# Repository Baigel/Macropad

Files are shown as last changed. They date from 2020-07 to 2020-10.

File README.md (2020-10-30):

This project is modified from Mattia Dal Ben's YamPad with a few changes that suit my specific needs (credit: https://github.com/mattdibi/yampad)

The Yampad project is an open-source, [QMK (Quantum Mechanical Keyboard Firmware)](https://github.com/qmk/qmk_firmware) powered, hot-swappable, RGB-backlighted, OLED featured, mechanical numpad.

## Primary Modifications from Original YamPad
 - Added 2 more switches for an array of 4x5 buttons (no more 2u keys)
 - Added spot for an IR sensor
 - Made the unused pins more accessible (added them as expansion pins on the side; with room for a decoupling capacitor)
 - Redid the PCB design (basically designed the PCB from scratch, used Mattia Dal Ben's design as a guide)
 - Different mounting holes (in hindsight, the Pro Micro may cover the holes in the top right - Oops!)

## YamPad Features:
- Cheap to build: the PCB can be manufactured for less than 1$ per piece.
- Easy to source components.
- Easy to build.
- Hot swappable keys using *Kailh PCB sockets*.
- Arduino Pro Micro powered.
- QMK compatible.
- RGB backlighting support (optional).
- OLED 0.91" screen (optional).
- Completely open-source.

## Bill of materials

| Qty | Item | Notes |
|-----|---|---|
| 1 | Arduino Pro Micro (ATmega32u4) | a.k.a. SparkFun Pro Micro |
| 20  | Cherry MX compatible switches | |
| 20  | SOD-123 1N4148/1N4148W diodes | |
| 20  | Kailh PCB sockets CPG151101S11 | |
| 10  | WS2812B RGB LEDs | |
| 10  | SMD 0805 100nF capacitors | |
| 1 | I2C 0.91" 128*32 OLED Display Module | The ones using SSD1306 driver IC over I2C |
| 1 | 6mm*6mm button switch | |
| 1 | YamPAD/Macropad PCB | |
| 5 | M3 screws | |

Note that I have included my personal shopping list (with links) in /Macropad/Bill_of_Materials.txt for reference

## Assembly guide

Not necessary to assemble in this order. More details can be found on the official YamPad repository (https://github.com/mattdibi/yampad).

1. Start with soldering the **WS2812 LEDs**. Start by applying solder to a pad, then heat it up while adding the component, finally solder the remaining pads.
2. Now add the **0805 100nF caps**. Use the same technique as before.
3. Add the **1N4148 diodes**.
4. Add the **CPG151101S11 Kailh PCB sockets**.
5. Add the **reset 6mm button switch**.
6. Add some electrical tape just to be sure.
7. Add the **Arduino Pro Micro** bottom side up.
8. Add the **OLED screen**
9. Move to the firmware section and you should be set!

## Firmware

For now the firmware is available through mattdibi's [QMK firmware repository fork](https://github.com/mattdibi/qmk_firmware/tree/yampad).

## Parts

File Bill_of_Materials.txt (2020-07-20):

JLCPCB
 - Custom PCBs from jlcpcb; the zip file that must be uploaded can be found at [https://github.com/Baigel/Macropad/blob/master/pcb/Macropad_Gerber_Files.zip]; the default settings on https://cart.jlcpcb.com/ are fine although the dimensions must be 100mm by 100mm

 SparkFun
 - Pro Micro (microcontroller) (a.k.a. SparkFun Pro Micro)
https://www.sparkfun.com/products/15795

 - 10x WS2812B RGB LEDs (I have included multiple sources below, digikey/sparkfun is easiest, but price/availability is a little iffy)
https://www.sparkfun.com/products/13667
https://core-electronics.com.au/smd-led-rgb-ws2812b-strip-of-10.html
https://www.digikey.com.au/product-detail/en/COM-16347/1568-COM-16347CT-ND/12149781/?itemSeq=332673955

KBD Fans
 - 20x Switches (Kailh Speed Copper) (each order comes with 10, so only need to set quantity to 2)
https://kbdfans.com/products/kailh-speed-switches?variant=7133813932090

 - 20x Kailh PCB sockets CPG151101S11
https://kbdfans.com/products/mechanical-keyboard-switches-kailh-pcb-socket

BangGood
 - 1x I2C 0.91" 128*32 OLED Display Module (The ones using SSD1306 driver IC over I2C)
https://au.banggood.com/0_91-Inch-128x32-IIC-I2C-Blue-OLED-LCD-Display-DIY-Oled-Module-SSD1306-Driver-IC-DC-3_3V-5V-p-1140506.html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

Digikey
 - 1x 6mm*6mm button switch
https://www.digikey.com.au/product-detail/en/e-switch/TL3342F160QG-TR/EG2531CT-ND/379004

 - 30x SMD 0805 100nF capacitors (10 spares because these are tiny/cheap and are easily lost)
https://www.digikey.com.au/product-detail/en/kemet/C0805C104Z5VACTU/399-1177-1-ND/411452

 - 30x SOD-123 Diodes (1 per switch) (1N4148W) (10 spares because these are tiny/cheap and are easily lost)
https://www.digikey.com.au/product-detail/en/diodes-incorporated/1N4148W-13-F/1N4148W-13FDICT-ND/2242774

 - 6x Standoffs: (not sure if this is what is needed, but with a couple of m3 screws you should be able to work something out)
https://www.digikey.com.au/product-detail/en/MTS-8/RPC1574-ND/392815/?itemSeq=332685766

Price Estimate: $5 [PCB] + $8 [standoffs] + 2x$20 [Pro Micro] + 2x$3 [Switches] + 20x$0.1 [Sockets] + $4 [OLED Display] + $1 [Reset Button] + 30x$0.15 [Capacitors] + 30x$0.25 [Diodes] + $9 [RGB LEDs] + $8 [Digikey Ruler] = $92

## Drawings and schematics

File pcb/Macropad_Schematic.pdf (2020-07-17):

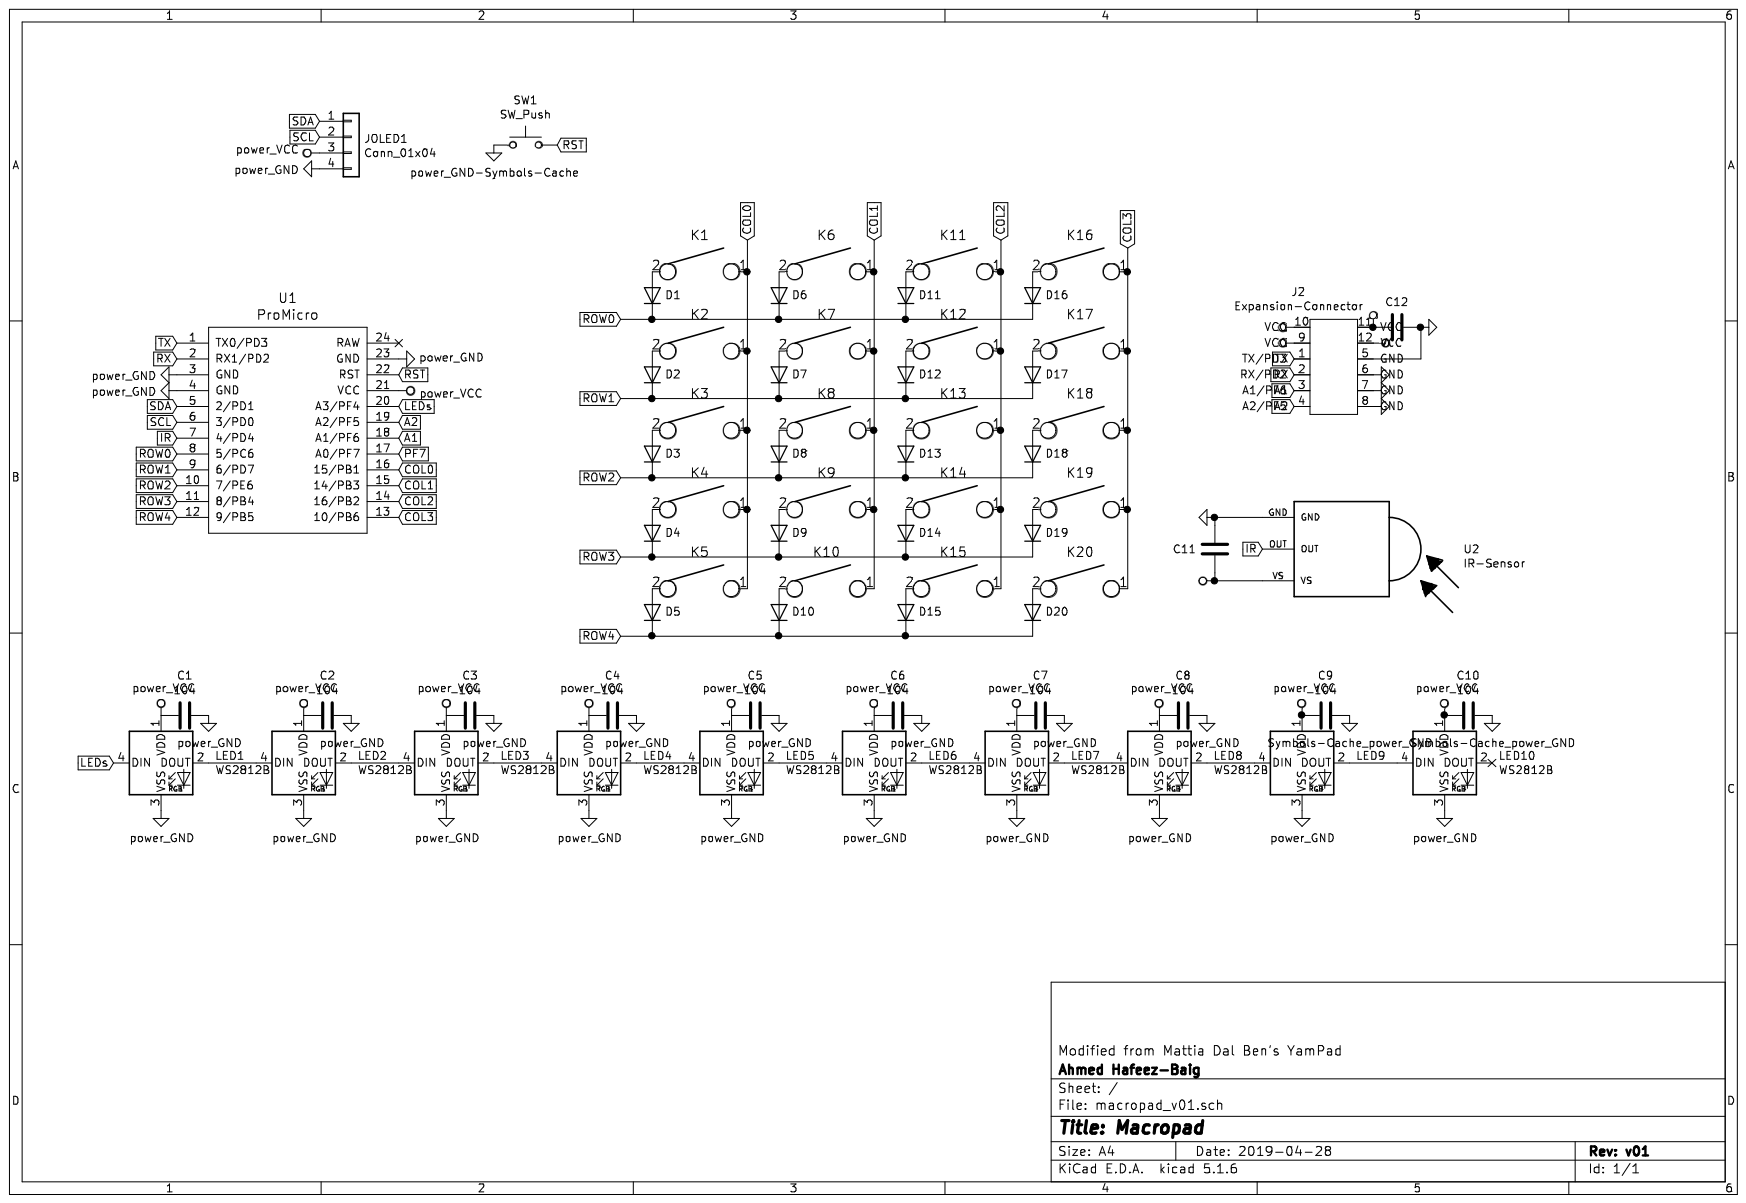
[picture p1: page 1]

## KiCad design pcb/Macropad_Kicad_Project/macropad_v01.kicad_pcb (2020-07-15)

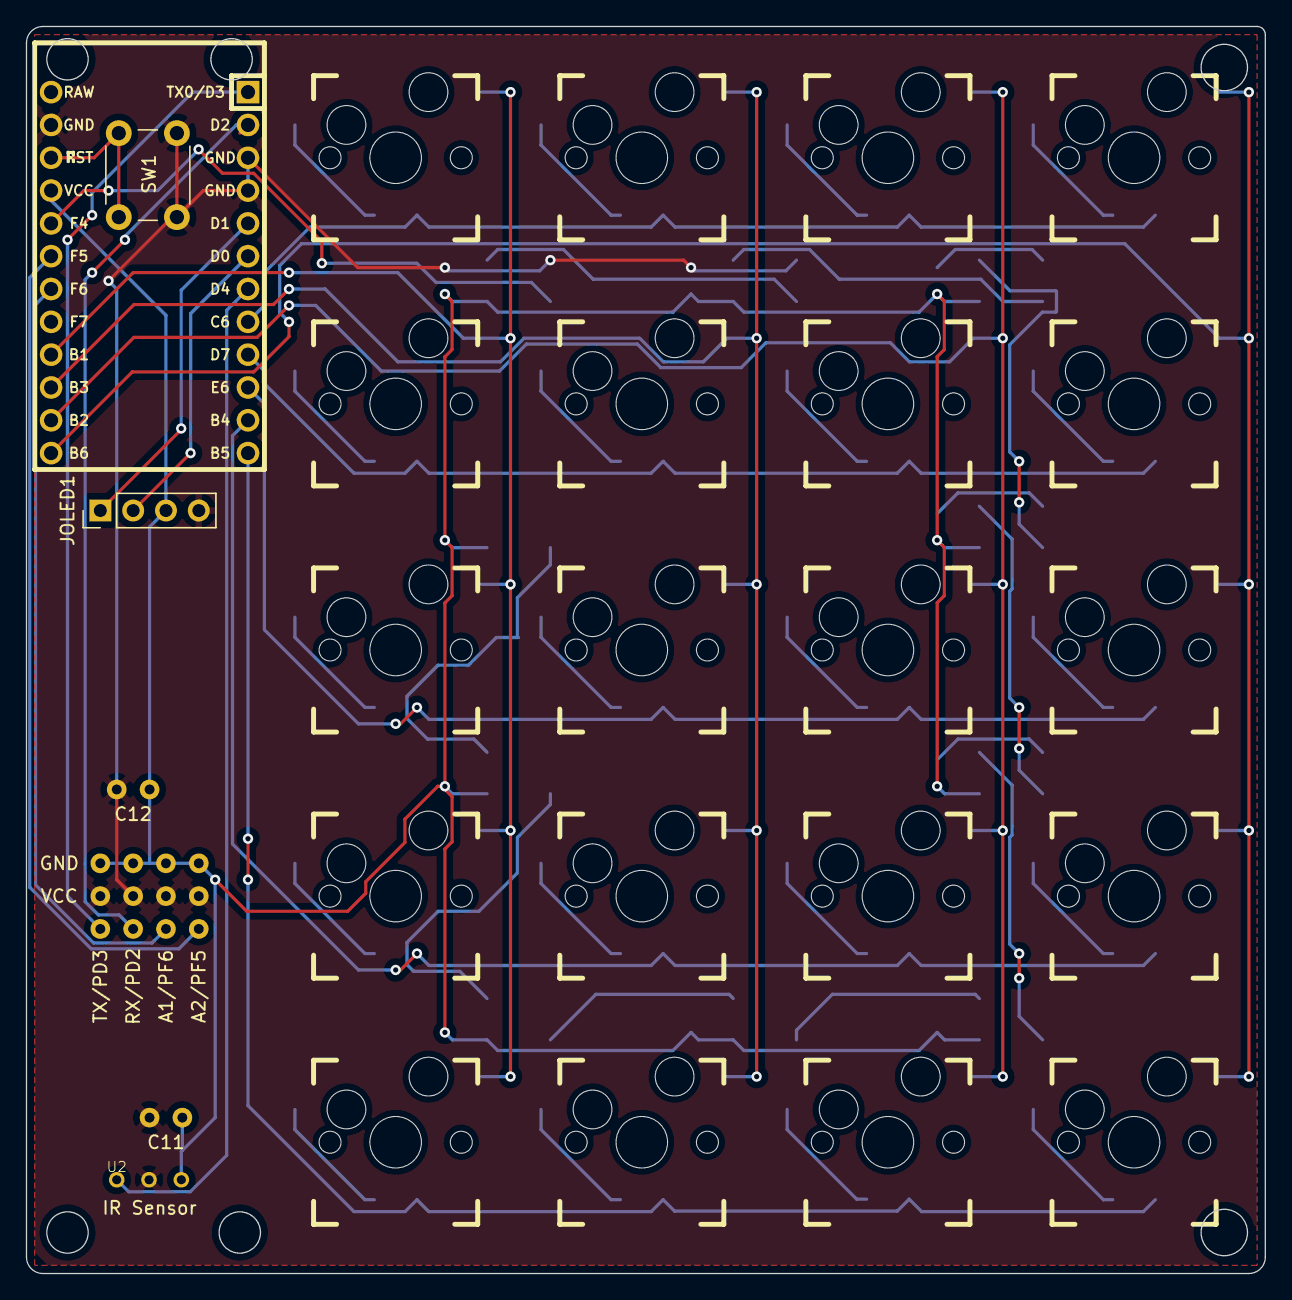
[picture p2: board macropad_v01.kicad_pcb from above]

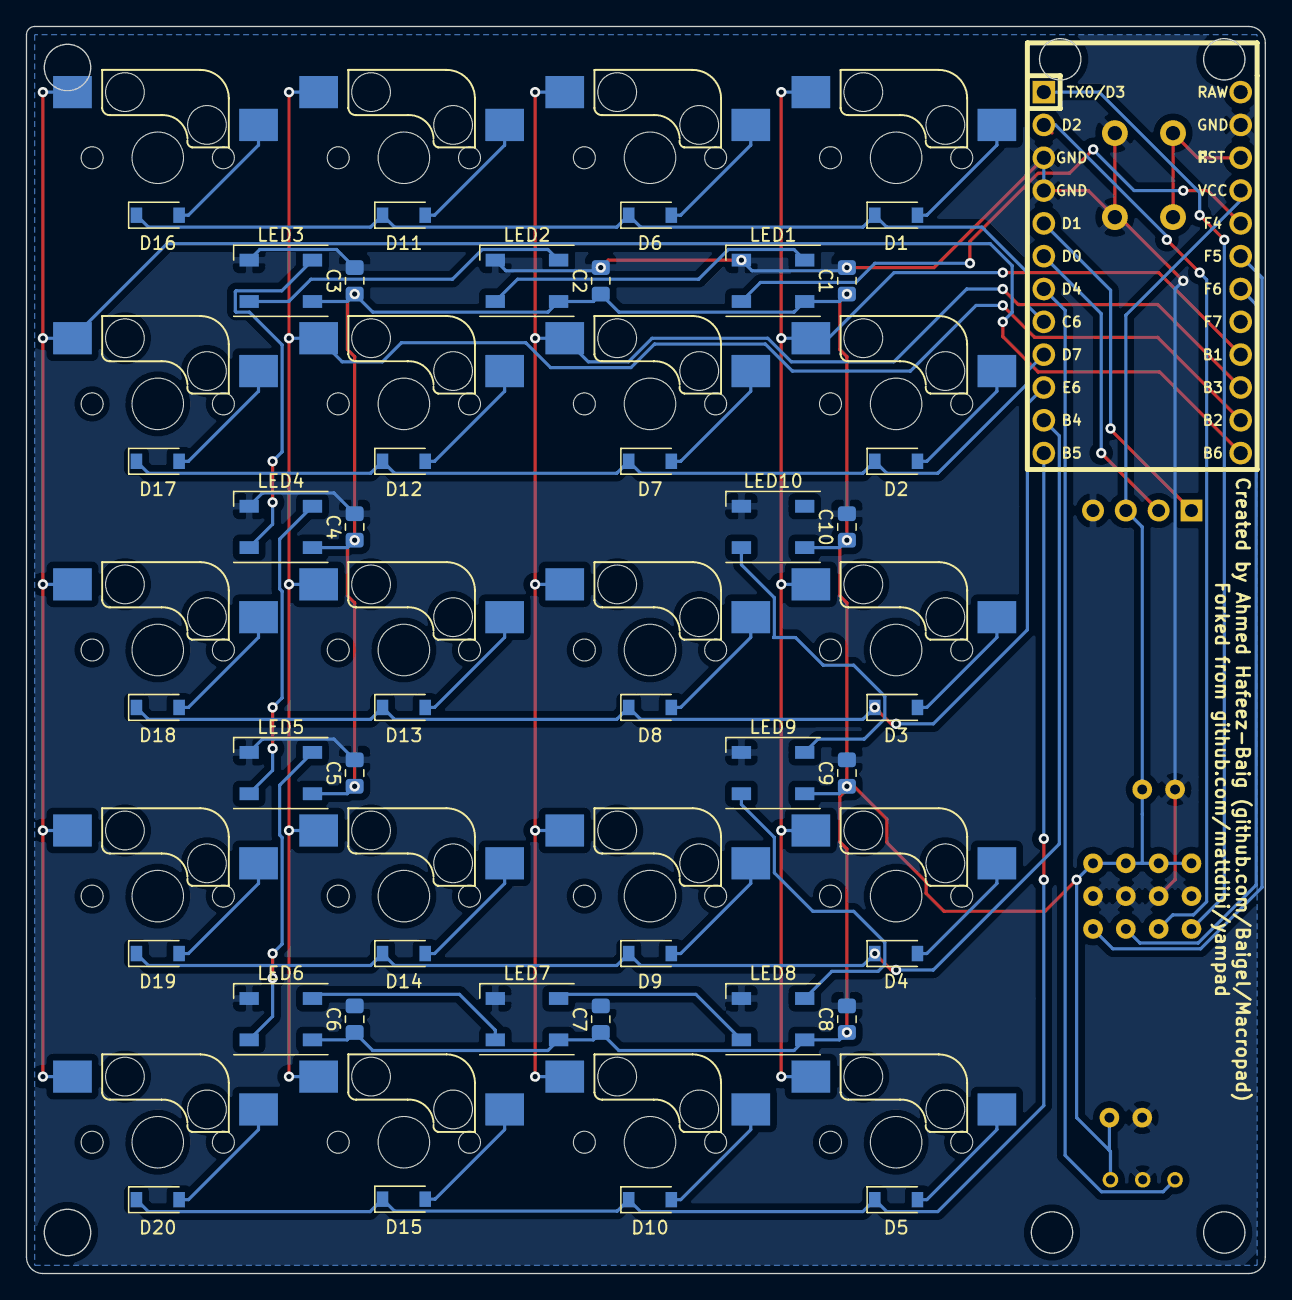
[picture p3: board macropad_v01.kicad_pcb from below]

Board: 2 copper layers, 95.9 x 96.5 mm, 67 parts (41 on the bottom side), 49 nets.

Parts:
C1, C2, C3, C4, C5, C6, C7, C8, C9, C10: 104; C_0805_2012Metric_Pad1.15x1.40mm_HandSolder
C11: macropad_v01-rescue_Symbols-Cache_Device_C-Symbol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; Capacitor-(100uF)
C12: Device_C-Symbols-Cache; Capacitor-(100uF)
D1, D2, D3, D4, D5, D6, D7, D8, D9, D10, D11, D12, D13, D14, D15, D16, D17, D18, D19, D20: D; D_SOD-123
J2: Expansion-Connector; Expansion-Pins
JOLED1: Conn_01x04; PinHeader_1x04_P2.54mm_Vertical
K1, K2, K3, K4, K5, K6, K7, K8, K9, K10, K11, K12, K13, K14, K15, K18, K19, K20: KEYSW; Kailh-PCB-Socket-1U-Cutout
K16, K17: KEYSW-canadian_parts-yampad_v2-rescue; Kailh-PCB-Socket-1U-Cutout
LED1, LED2, LED3, LED4, LED5, LED6, LED7, LED8, LED9, LED10: WS2812B; LED_WS2812B_PLCC4_5.0x5.0mm_P3.2mm
SW1: SW_Push; SW_PUSH_6mm
U1: ProMicro; ArduinoProMicro
U2: IR-Sensor; TSOP-382

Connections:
A1: J2.3, U1.18
A2: J2.4, U1.19
COL0: K1.1, K2.1, K3.1, K4.1, K5.1, U1.16
COL1: K6.1, K7.1, K8.1, K9.1, K10.1, U1.15
COL2: K11.1, K12.1, K13.1, K14.1, K15.1, U1.14
COL3: K16.1, K17.1, K18.1, K19.1, K20.1, U1.13
GND: C1.1, C2.1, C3.1, C4.1, C5.1, C6.1, C7.1, C8.1, C9.1, C10.1, C11.1, C12.1, J2.5, J2.6, J2.7, J2.8, JOLED1.4, LED1.3, LED2.3, LED3.3, LED4.3, LED5.3, LED6.3, LED7.3, LED8.3, LED9.3, LED10.3, SW1.1, U1.3, U1.4, U1.23, U2.GND
IR: U1.7, U2.OUT
LEDs: LED1.4, U1.20
unnamed: D1.2, K1.2
unnamed: D2.2, K2.2
unnamed: D3.2, K3.2
unnamed: D4.2, K4.2
unnamed: D5.2, K5.2
unnamed: D6.2, K6.2
unnamed: D7.2, K7.2
unnamed: D8.2, K8.2
unnamed: D9.2, K9.2
unnamed: D10.2, K10.2
unnamed: D11.2, K11.2
unnamed: D12.2, K12.2
unnamed: D13.2, K13.2
unnamed: D14.2, K14.2
unnamed: D15.2, K15.2
unnamed: D16.2, K16.2
unnamed: D17.2, K17.2
unnamed: D18.2, K18.2
unnamed: D19.2, K19.2
unnamed: D20.2, K20.2
unnamed: LED1.2, LED2.4
unnamed: LED2.2, LED3.4
unnamed: LED3.2, LED4.4
unnamed: LED4.2, LED5.4
unnamed: LED5.2, LED6.4
unnamed: LED6.2, LED7.4
unnamed: LED7.2, LED8.4
unnamed: LED8.2, LED9.4
unnamed: LED9.2, LED10.4
ROW0: D1.1, D6.1, D11.1, D16.1, U1.8
ROW1: D2.1, D7.1, D12.1, D17.1, U1.9
ROW2: D3.1, D8.1, D13.1, D18.1, U1.10
ROW3: D4.1, D9.1, D14.1, D19.1, U1.11
ROW4: D5.1, D10.1, D15.1, D20.1, U1.12
RST: SW1.2, U1.22
RX: J2.2, U1.2
SCL: JOLED1.2, U1.6
SDA: JOLED1.1, U1.5
TX: J2.1, U1.1
VCC: C1.2, C2.2, C3.2, C4.2, C5.2, C6.2, C7.2, C8.2, C9.2, C10.2, C11.2, C12.2, J2.9, J2.10, J2.11, J2.12, JOLED1.3, LED1.1, LED2.1, LED3.1, LED4.1, LED5.1, LED6.1, LED7.1, LED8.1, LED9.1, LED10.1, U1.21, U2.VS

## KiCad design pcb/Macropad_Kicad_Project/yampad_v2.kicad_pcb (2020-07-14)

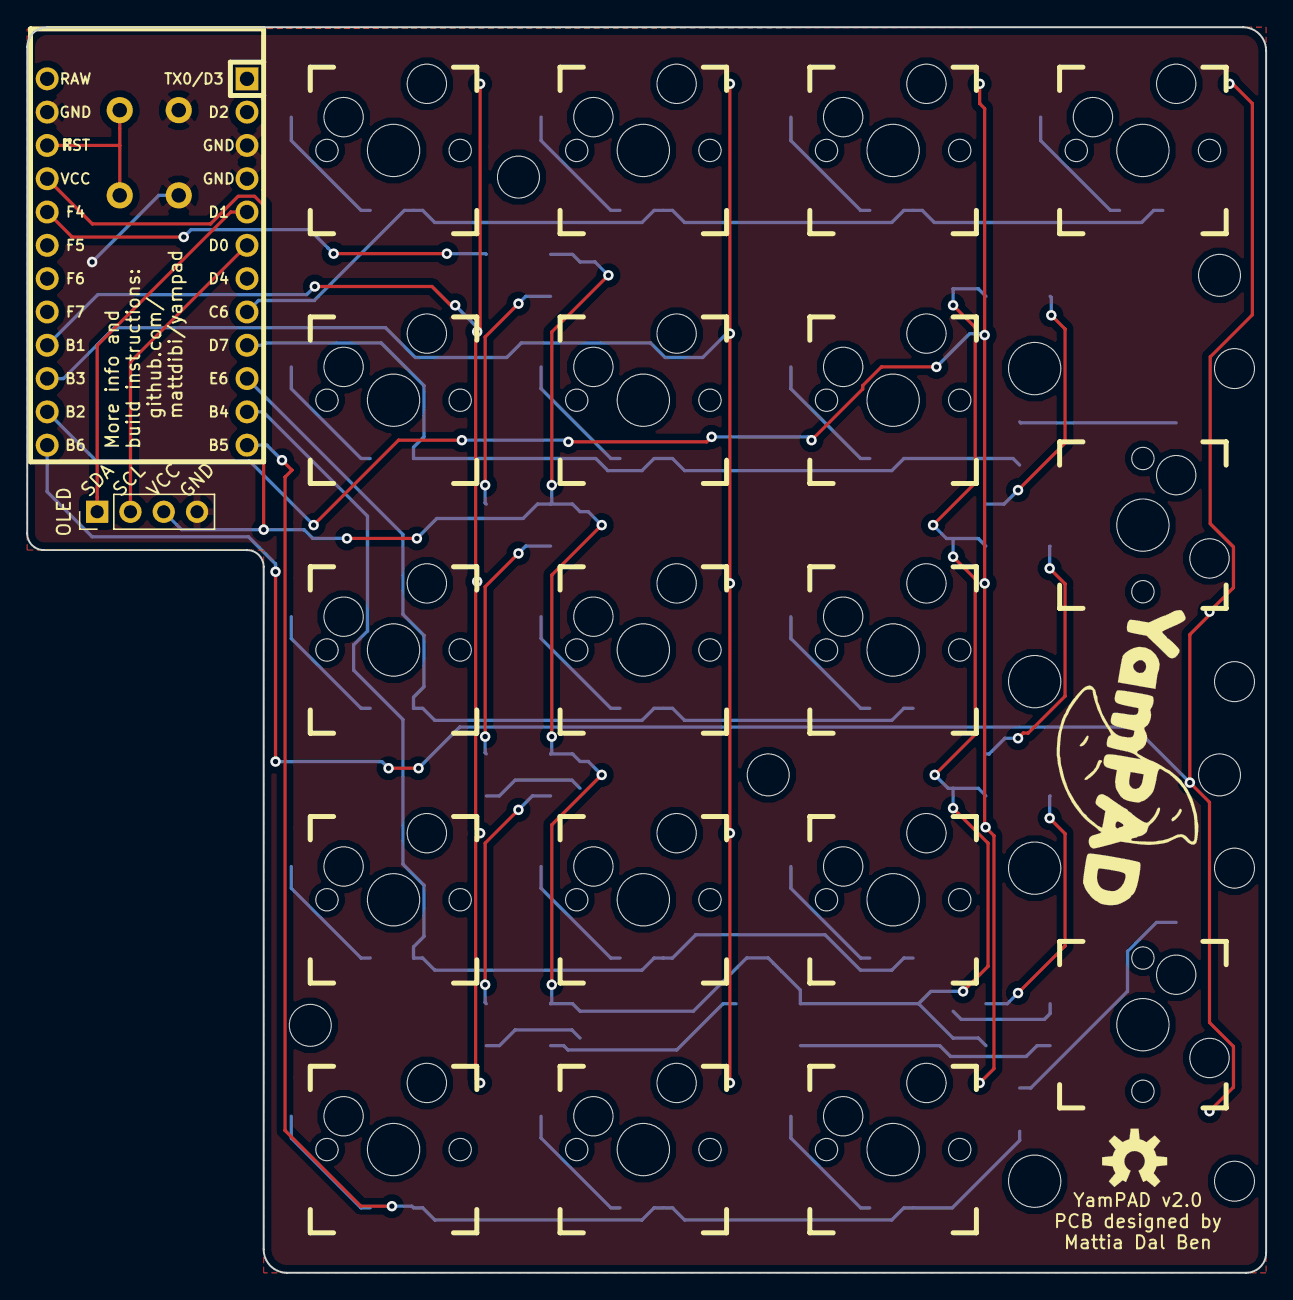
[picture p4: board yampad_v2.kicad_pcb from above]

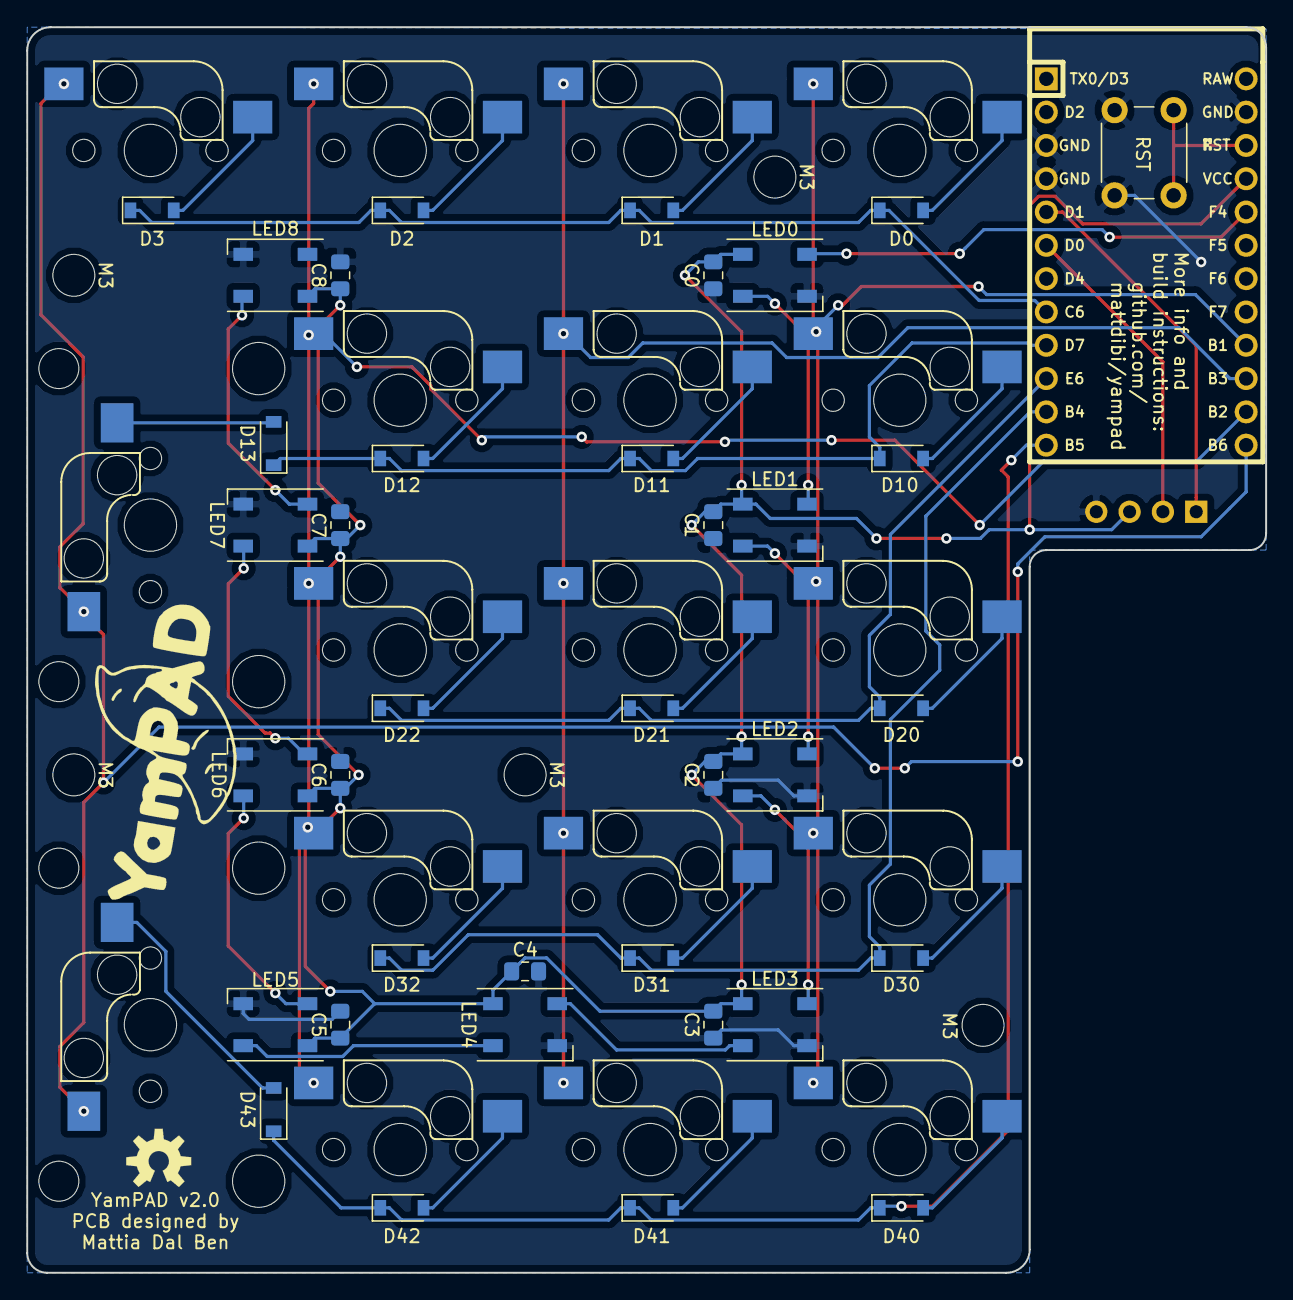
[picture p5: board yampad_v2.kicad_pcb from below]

Board: 2 copper layers, 94.5 x 95.0 mm, 62 parts (43 on the bottom side), 41 nets.

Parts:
C0, C1, C2, C3, C4, C5, C6, C7, C8: 104; C_0805_2012Metric_Pad1.15x1.40mm_HandSolder
D0, D1, D2, D3, D10, D11, D12, D13, D20, D21, D22, D30, D31, D32, D40, D41, D42, D43: D; D_SOD-123
K0, K1, K2, K3, K10, K11, K12, K20, K21, K22, K30, K31, K32, K40, K41, K42: KEYSW; Kailh-PCB-Socket-1U-Cutout
K13, K43: KEYSW; Kailh-PCB-Socket-2U
LED0, LED1, LED2, LED3, LED4, LED5, LED6, LED7, LED8: WS2812B; LED_WS2812B_PLCC4_5.0x5.0mm_P3.2mm
M3, M3#2, M3#3, M3#4, M3#5: MountingHole_3.2mm_M3
OLED: Conn_01x04; PinHeader_1x04_P2.54mm_Vertical
RST: SW_Push; SW_PUSH_6mm
U0: ProMicro; ArduinoProMicro

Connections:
COL0: K0.1, K10.1, K20.1, K30.1, K40.1, U0.16
COL1: K1.1, K11.1, K21.1, K31.1, K41.1, U0.15
COL2: K2.1, K12.1, K22.1, K32.1, K42.1, U0.14
COL3: K3.1, K13.1, K43.1, U0.13
GND: C0.1, C1.1, C2.1, C3.1, C4.1, C5.1, C6.1, C7.1, C8.1, LED0.3, LED1.3, LED2.3, LED3.3, LED4.3, LED5.3, LED6.3, LED7.3, LED8.3, OLED.4, RST.1, U0.3, U0.4, U0.23
LEDs: LED0.4, U0.20
unnamed: D0.2, K0.2
unnamed: D1.2, K1.2
unnamed: D2.2, K2.2
unnamed: D3.2, K3.2
unnamed: D10.2, K10.2
unnamed: D11.2, K11.2
unnamed: D12.2, K12.2
unnamed: D13.2, K13.2
unnamed: D20.2, K20.2
unnamed: D21.2, K21.2
unnamed: D22.2, K22.2
unnamed: D30.2, K30.2
unnamed: D31.2, K31.2
unnamed: D32.2, K32.2
unnamed: D40.2, K40.2
unnamed: D41.2, K41.2
unnamed: D42.2, K42.2
unnamed: D43.2, K43.2
unnamed: LED0.2, LED1.4
unnamed: LED1.2, LED2.4
unnamed: LED2.2, LED3.4
unnamed: LED3.2, LED4.4
unnamed: LED4.2, LED5.4
unnamed: LED5.2, LED6.4
unnamed: LED6.2, LED7.4
unnamed: LED7.2, LED8.4
ROW0: D0.1, D1.1, D2.1, D3.1, U0.8
ROW1: D10.1, D11.1, D12.1, D13.1, U0.9
ROW2: D20.1, D21.1, D22.1, U0.10
ROW3: D30.1, D31.1, D32.1, U0.11
ROW4: D40.1, D41.1, D42.1, D43.1, U0.12
RST: RST.2, U0.22
SCL: OLED.2, U0.6
SDA: OLED.1, U0.5
VCC: C0.2, C1.2, C2.2, C3.2, C4.2, C5.2, C6.2, C7.2, C8.2, LED0.1, LED1.1, LED2.1, LED3.1, LED4.1, LED5.1, LED6.1, LED7.1, LED8.1, OLED.3, U0.21

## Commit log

2020-06-30 Update README.md
    Took out a lot of the stuff that was in the original YamPad repo (just to cut down on stuff that I don't need) - if you want more details go visit the original repo.
2020-07-14 Working on PCB
    Still to do:
    - Add decoupling resistor to IR sensor
    - Add decoupling resistor place for extra pins
    - Complete PCB (still laying out things)
    - Do all the wire runs for the PCB
    [macropad_v01.kicad_pcb, macropad_v01.sch, yampad_v2.kicad_pcb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]
2020-07-15 PCB DONE!!!
    (i think)
    [macropad_v01.kicad_pcb, macropad_v01.sch, yampad_v2.kicad_pcb]
2020-07-15 Generated Gerber
    probs should redo the way jlcpcb wants it done
    [macropad_v01-B_Cu.gbl, macropad_v01-B_Mask.gbs, macropad_v01-B_Paste.gbp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]
2020-07-17 commited gerber files (the correct ones needed for jlcpcb)
    [macropad_v01-B_Cu.gbl, macropad_v01-B_Mask.gbs, macropad_v01-B_Paste.gbp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]
2020-07-20 Update README.md
    finished the PCB design, so I have just polished the readme a bit
2020-10-30 Fixed number of items in BOM to better represent macropad
